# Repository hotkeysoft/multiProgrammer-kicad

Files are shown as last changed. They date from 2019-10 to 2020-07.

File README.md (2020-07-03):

# Multi-Programmer With Serial / SPI Programming
Rev A August 2019

Features
============
- Sockets for direct programming:
	- ATMEGA328P TQFP 32 (via adapter)
	- ATMEGA328P DIP 28 pins
	- ATTINY44/84
	- ATTINY45/85
- Headers for in-circuit programming:
	- Serial Header:
		- 5 pins 2.54mm
	- SPI Headers (too many):
		- 2x3 pins 2.54mm (99% of use)
		- 2x3 pins 1.27mm
		- 1x6 pins 1.25mm (micro-JST)
		- Tag-Connect (mostly useless, since there are no two-ended 
		  Tag-Connect cables. Will be removed in future revisions)
- Two programming modes:
	- Serial passtrough
		- Useful to programm chips with Arduino bootloader, or for any USB<->Serial adapter needs
	- ICSP Programming
		- Compatible with _Arduino as ISP_ programmer in Arduino interface
	- Toggle Serial/ICSP mode with pushbutton switch
- USB-B port (could be a downside but I am fond of them: they are sturdy)

Notes
============
- Socketed chips:
	- _ATmega328P_ running _ArduinoISP_
	- _555_ Used for Mode switch debouncing (old school)
	- _PALCE16V8_ for mode switching logic (LEDs, pin routing) [source](PLD/TTLSW.PDS) 
- Optional crystal socket, not needed for new chips (internal clock is used)
 	- Required for serial programming if the target is set to use an external crystal
	  (Need to confirm if needed in SPI mode)
- Boots in serial mode, be sure to switch mode to use SPI mode
- Reset button resets the target chip (in both modes) and the _Arduino as ISP_ software
- Don't put more than one target chip at a time (undefined behavior, no protection, might destroy the universe)

Images
============

|Render | Real PCB |
|---|---|
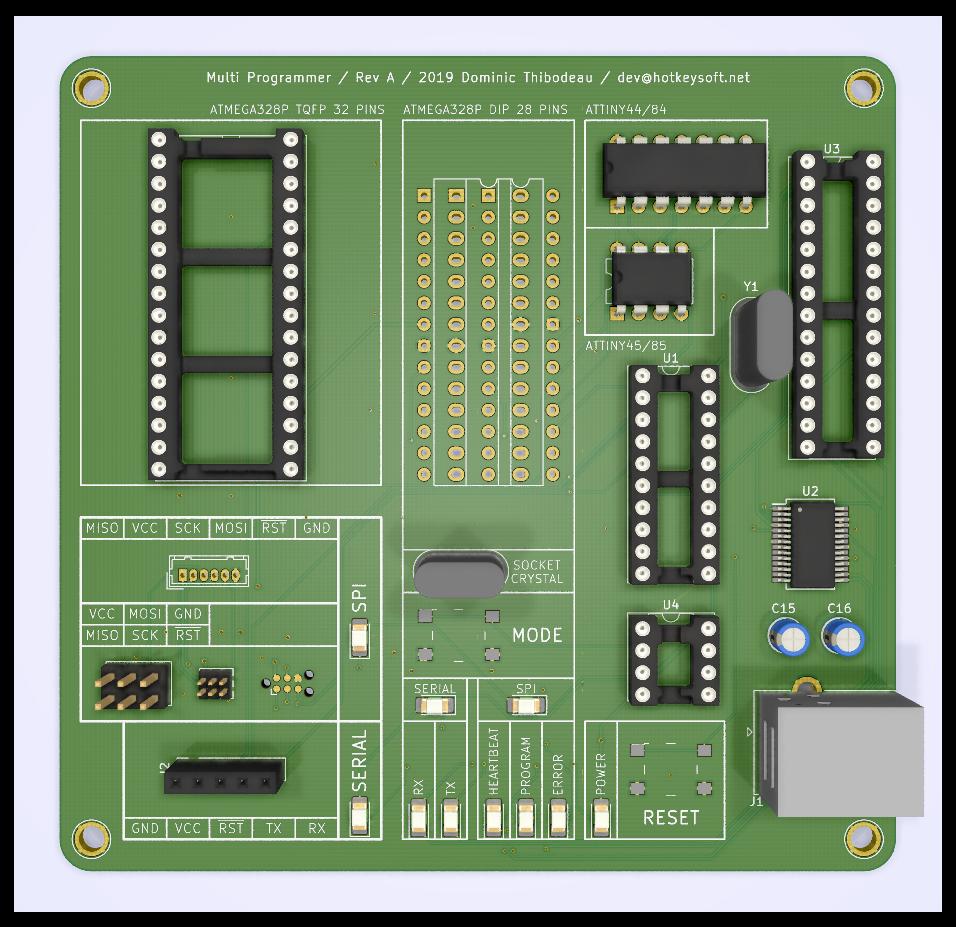
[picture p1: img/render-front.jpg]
Render Front
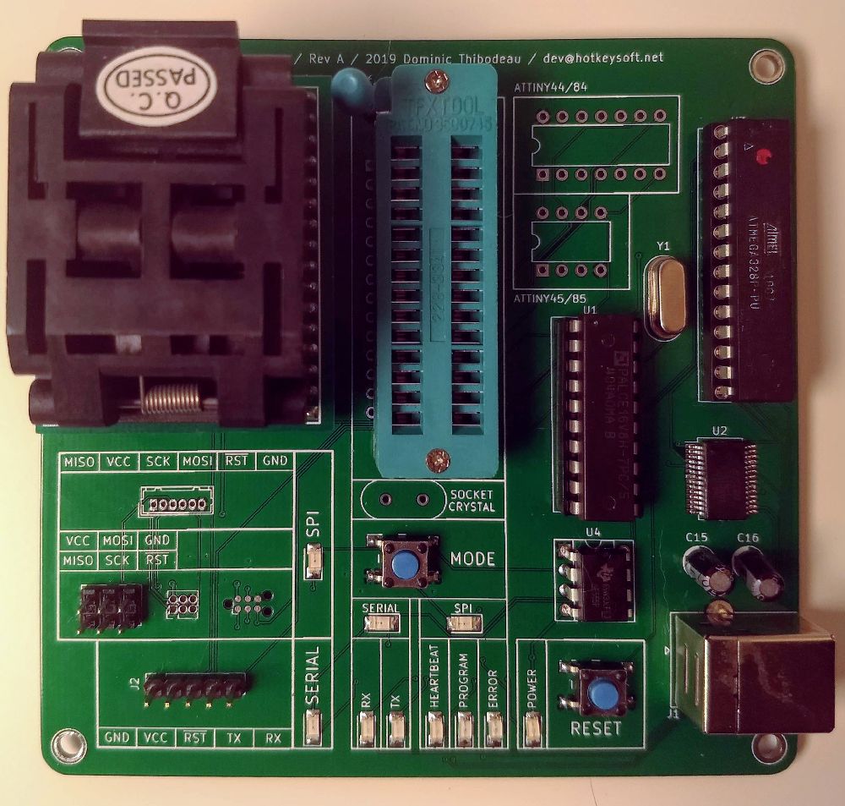
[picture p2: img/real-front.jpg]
Real Front
|||
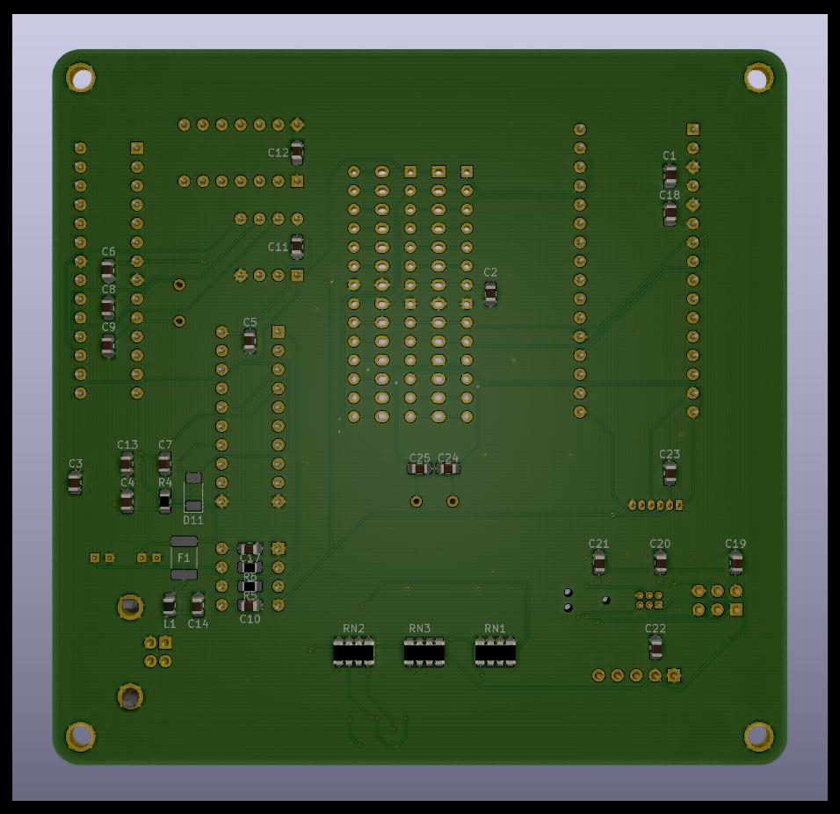
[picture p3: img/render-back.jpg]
Render Back
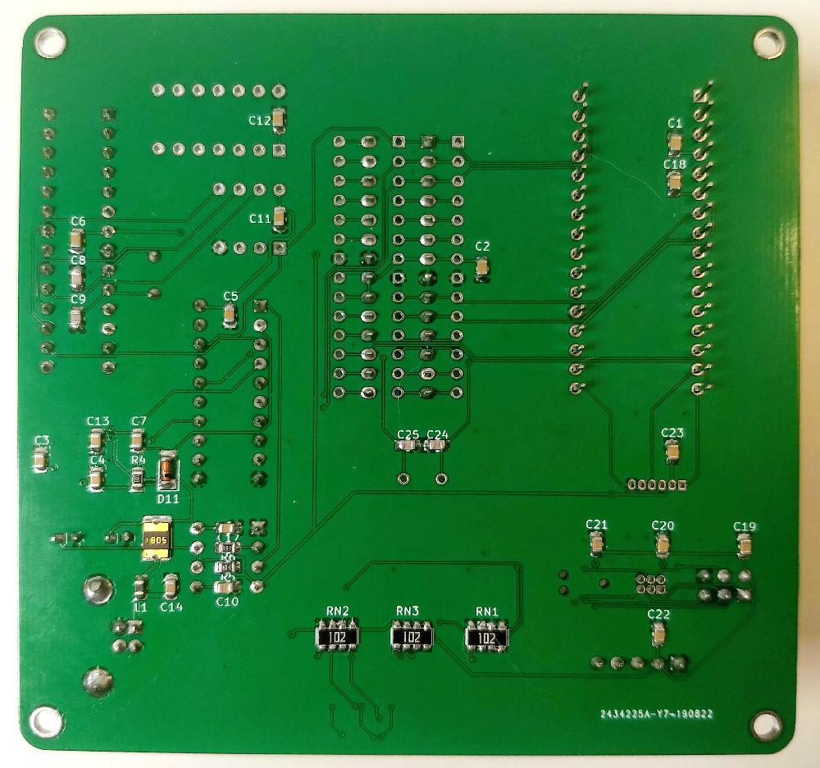
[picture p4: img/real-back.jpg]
Real Back
| | |

### Schematics (pdf)
- [Complete schematics](./img/schema.pdf)

### PCB Images (svg)
- [Top](./img/pcb-front.svg)
- [Bottom](./img/pcb-back.svg)

Future
============
- Try to combine 555 and programmable logic on Arduino
- Remove useless connectors
- Save mode in EEPROM so it is remembered on next power-up
- LEDs are too bright

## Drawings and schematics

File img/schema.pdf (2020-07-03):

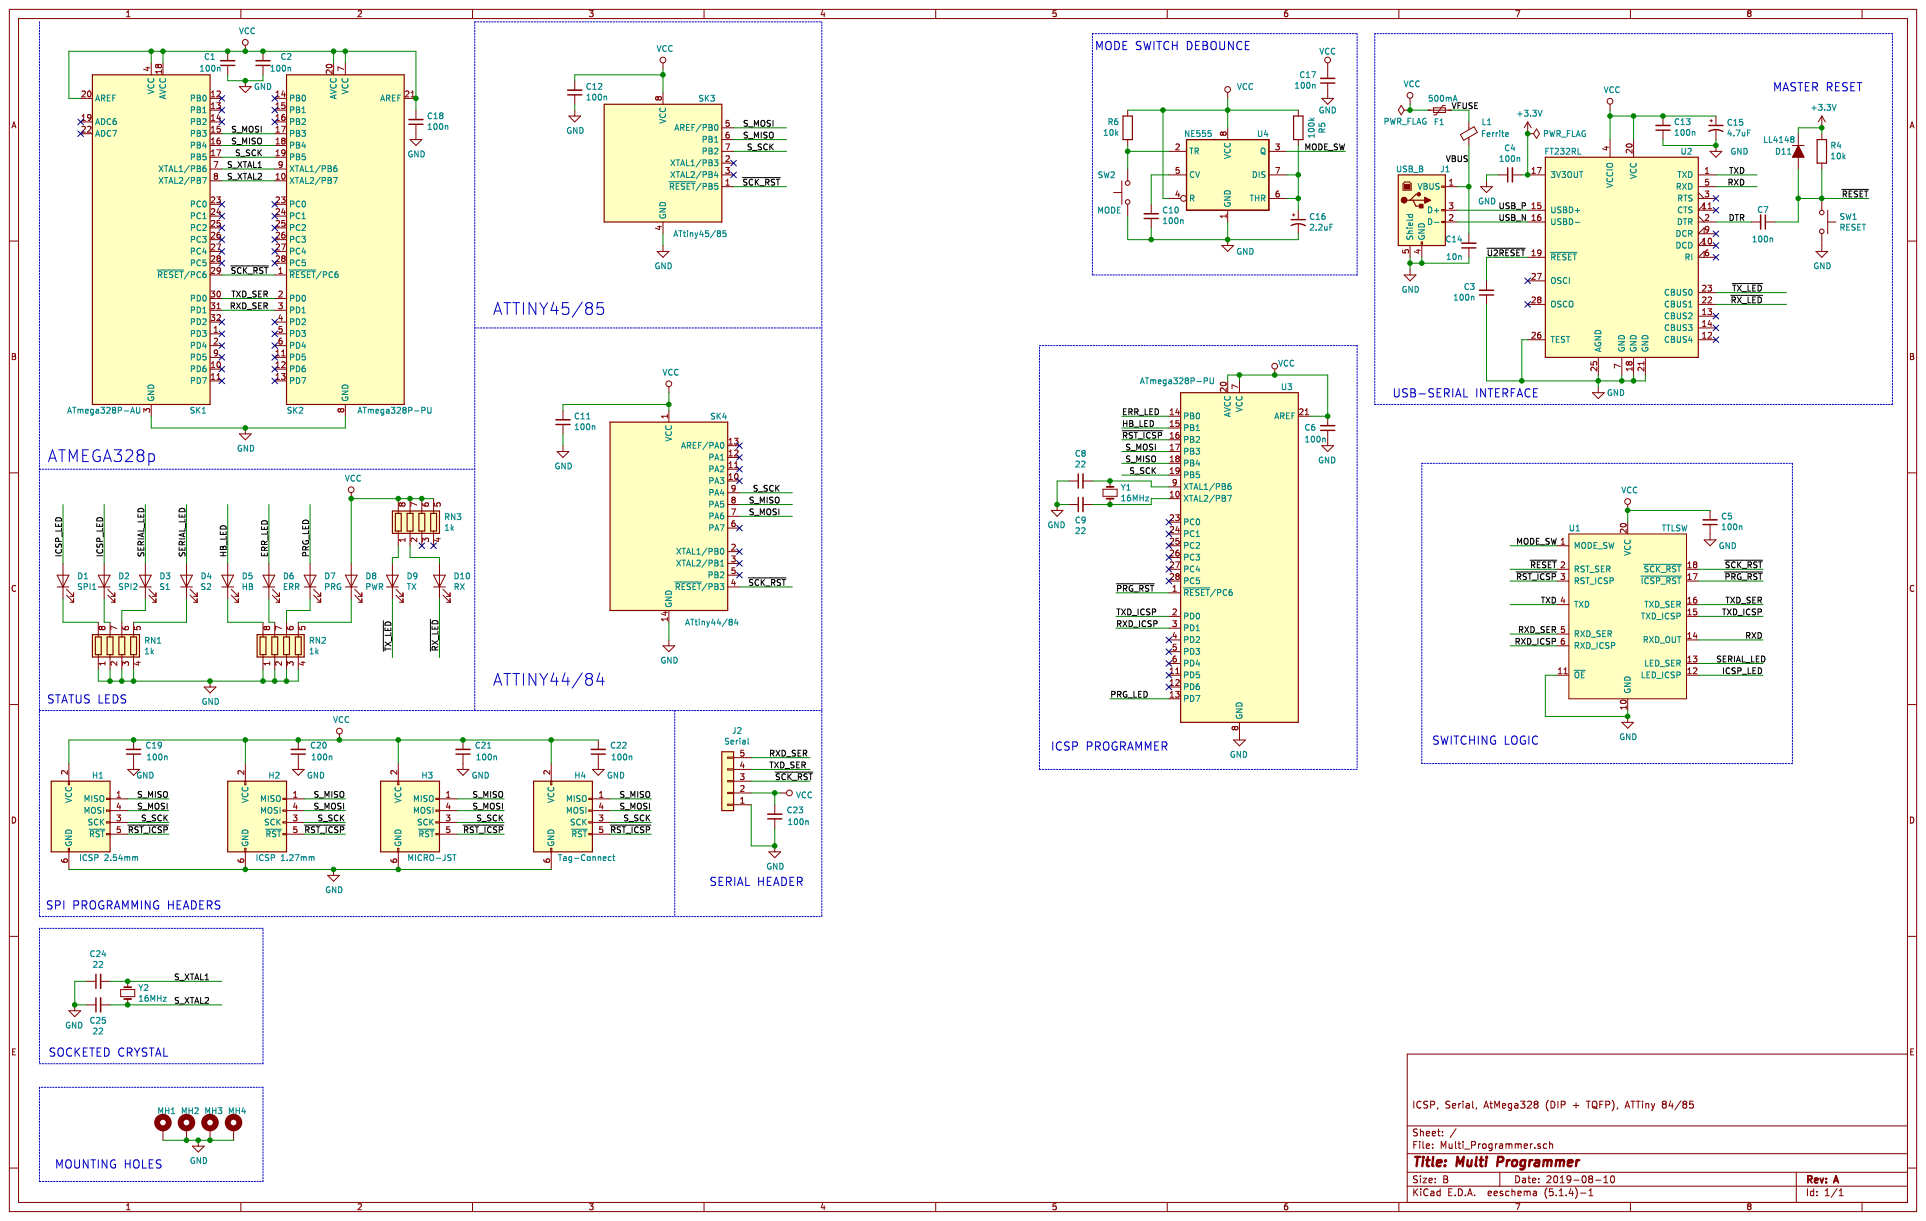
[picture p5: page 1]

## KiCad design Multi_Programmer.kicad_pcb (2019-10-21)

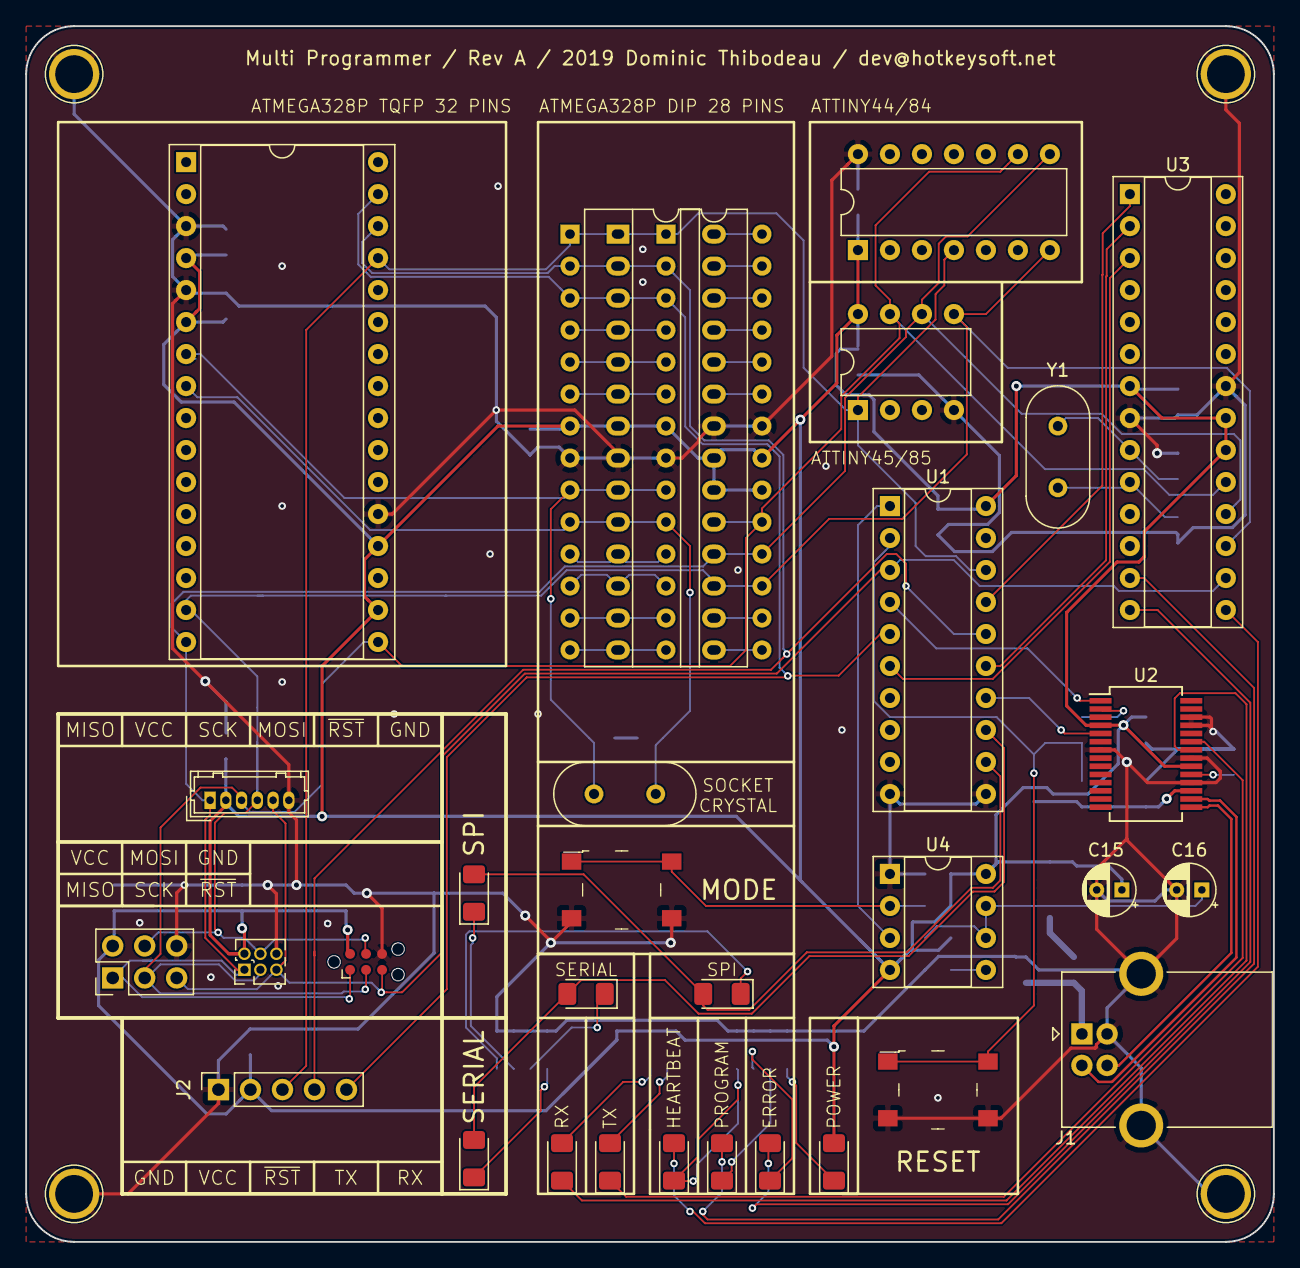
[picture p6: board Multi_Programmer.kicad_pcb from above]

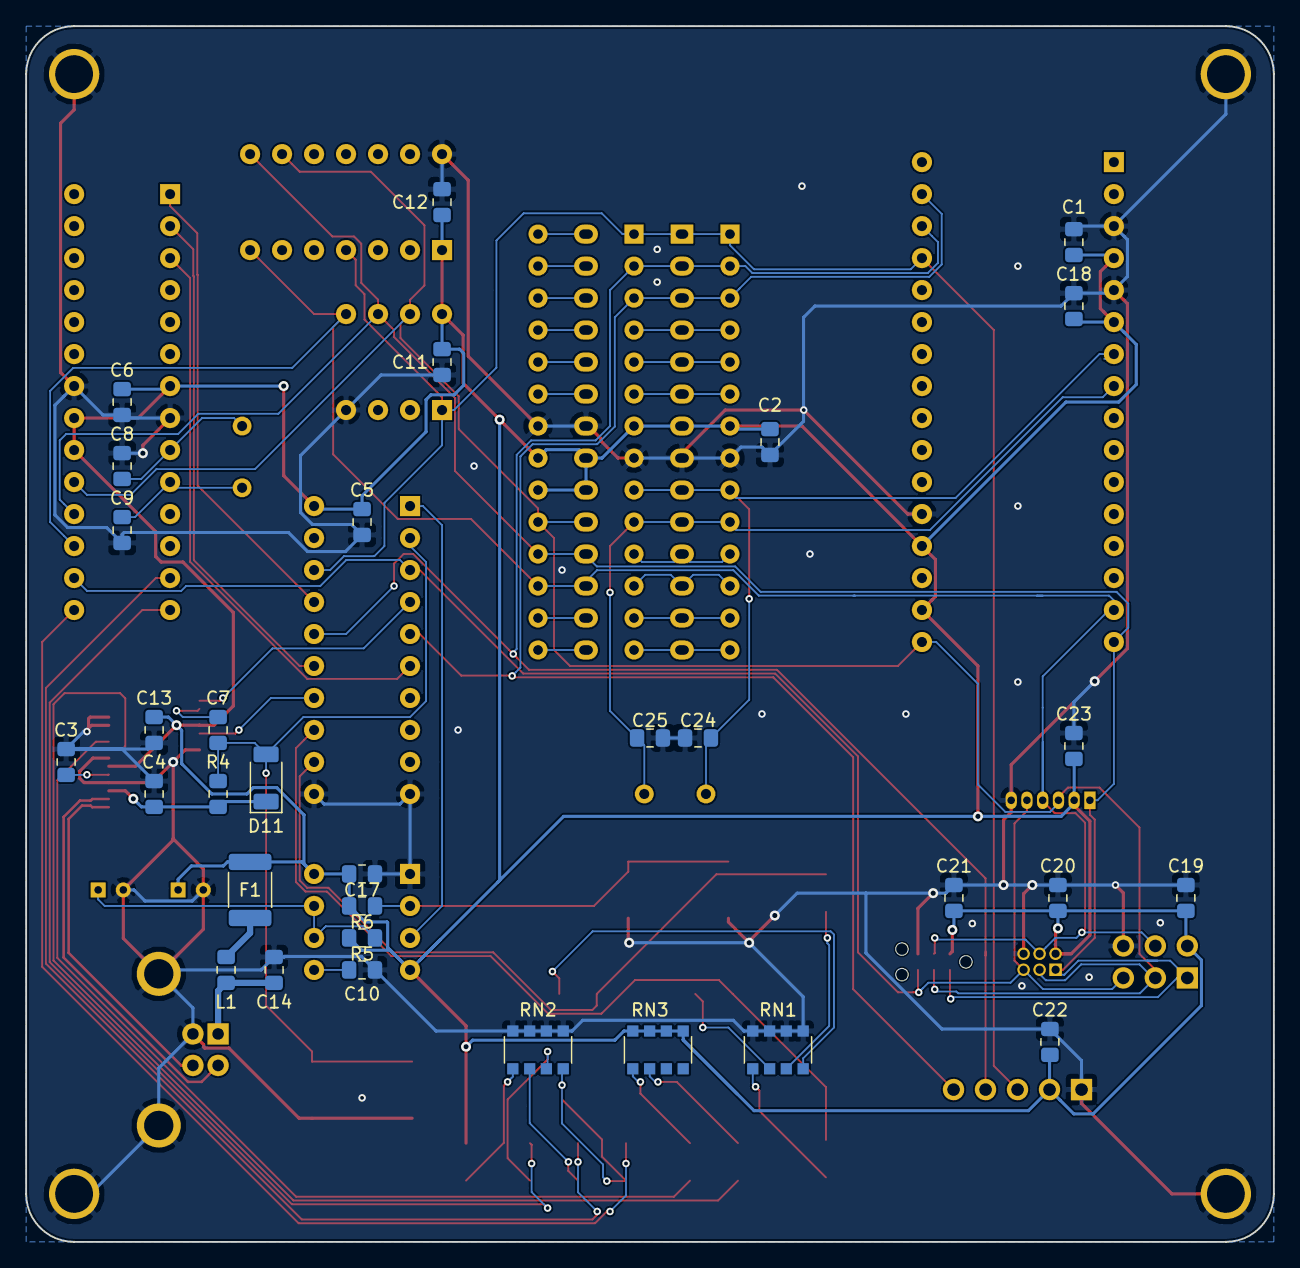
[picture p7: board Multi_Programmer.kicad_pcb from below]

Board: 2 copper layers, 99.1 x 96.5 mm, 66 parts (32 on the bottom side), 47 nets.

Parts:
C1, C2, C3, C4, C5, C6, C7, C10, C11, C12, C13, C17, C18, C19, C20, C21, C22, C23: 100n; C_0805_2012Metric_Pad1.15x1.40mm_HandSolder
C8, C9, C24, C25: 22; C_0805_2012Metric_Pad1.15x1.40mm_HandSolder
C14: 10n; C_0805_2012Metric_Pad1.15x1.40mm_HandSolder
C15: 4.7uF; CP_Radial_D4.0mm_P2.00mm
C16: 2.2uF; CP_Radial_D4.0mm_P2.00mm
D1: SPI1; LED_1206_3216Metric_Pad1.42x1.75mm_HandSolder
D2: SPI2; LED_1206_3216Metric_Pad1.42x1.75mm_HandSolder
D3: S1; LED_1206_3216Metric_Pad1.42x1.75mm_HandSolder
D4: S2; LED_1206_3216Metric_Pad1.42x1.75mm_HandSolder
D5: HB; LED_1206_3216Metric_Pad1.42x1.75mm_HandSolder
D6: ERR; LED_1206_3216Metric_Pad1.42x1.75mm_HandSolder
D7: PRG; LED_1206_3216Metric_Pad1.42x1.75mm_HandSolder
D8: PWR; LED_1206_3216Metric_Pad1.42x1.75mm_HandSolder
D9: TX; LED_1206_3216Metric_Pad1.42x1.75mm_HandSolder
D10: RX; LED_1206_3216Metric_Pad1.42x1.75mm_HandSolder
D11: LL4148; SOD80
F1: 500mA; Fuse_1812_4532Metric_Pad1.30x3.40mm_HandSolder
H1: ICSP 2.54mm; PinHeader_2x03_P2.54mm_Vertical
H2: ICSP 1.27mm; PinHeader_2x03_P1.27mm_Vertical
H3: MICRO-JST; Hirose_DF13-06P-1.25DSA_1x06_P1.25mm_Vertical
H4: Tag-Connect; Tag-Connect_TC2030-IDC-NL_2x03_P1.27mm_Vertical
J1: USB_B; USB_B_OST_USB-B1HSxx_Horizontal
J2: Serial; PinSocket_1x05_P2.54mm_Vertical
L1: Ferrite; L_0805_2012Metric_Pad1.15x1.40mm_HandSolder
MH1, MH2, MH3, MH4: MountingHole; TestPoint_Plated_Hole_D3.0mm
R4, R6: 10k; R_0805_2012Metric_Pad1.15x1.40mm_HandSolder
R5: 100k; R_0805_2012Metric_Pad1.15x1.40mm_HandSolder
RN1, RN2, RN3: 1k; R_Array_Convex_4x1206
SK1: ATmega328P-AU; DIP-32_W15.24mm_Socket
SK2: ATmega328P-PU; DIP-28_Zif_Multi
SK3: ATtiny45/85; DIP-8_W7.62mm
SK4: ATtiny44/84; DIP-14_W7.62mm
SW1: RESET; Switch_Tactile_SMD_6x6mm_PTS645
SW2: MODE; Switch_Tactile_SMD_6x6mm_PTS645
U1: TTLSW; DIP-20_W7.62mm_Socket
U2: FT232RL; SSOP-28_5.3x10.2mm_P0.65mm
U3: ATmega328P-PU; DIP-28_W7.62mm_Socket
U4: NE555; DIP-8_W7.62mm_Socket
Y1, Y2: 16MHz; Crystal_HC18-U_Vertical

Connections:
+3V3: C4.2, D11.1, R4.2, U2.17
/DTR: C7.2, U2.2
/ERR_LED: D6.2, U3.14
/HB_LED: D5.2, U3.15
/ICSP_LED: D1.2, D2.2, U1.12
/MODE_SW: U1.1, U4.3
/PRG_LED: D7.2, U3.13
/RXD: U1.14, U2.5
/RXD_ICSP: U1.6, U3.3
/RXD_SER: J2.5, SK1.31, SK2.3, U1.5
/SERIAL_LED: D3.2, D4.2, U1.13
/S_MISO: H1.1, H2.1, H3.1, H4.1, SK1.16, SK2.18, SK3.6, SK4.8, U3.18
/S_MOSI: H1.4, H2.4, H3.4, H4.4, SK1.15, SK2.17, SK3.5, SK4.7, U3.17
/S_SCK: H1.3, H2.3, H3.3, H4.3, SK1.17, SK2.19, SK3.7, SK4.9, U3.19
/S_XTAL1: C24.2, SK1.7, SK2.9, Y2.1
/S_XTAL2: C25.2, SK1.8, SK2.10, Y2.2
/TXD: U1.4, U2.1
/TXD_ICSP: U1.15, U3.2
/TXD_SER: J2.4, SK1.30, SK2.2, U1.16
/USB_N: J1.2, U2.16
/USB_P: J1.3, U2.15
/VBUS: C14.2, J1.1, L1.2
/VFUSE: F1.1, L1.1
/~PRG_RST: U1.17, U3.1
/~RESET: C7.1, D11.2, R4.1, SW1.1, U1.2
/~RST_ICSP: H1.5, H2.5, H3.5, H4.5, U1.3, U3.16
/~RX_LED: D10.1, U2.22
/~SCK_RST: J2.3, SK1.29, SK2.1, SK3.1, SK4.4, U1.18
/~TX_LED: D9.1, U2.23
/~U2RESET: C3.2, U2.19
GND: C1.1, C2.1, C3.1, C4.1, C5.1, C6.1, C8.1, C9.1, C10.1, C11.1, C12.1, C13.1, C14.1, C15.2, C16.2, C17.1, C18.1, C19.1, C20.1, C21.1, C22.1, C23.1, C24.1, C25.1, H1.6, H2.6, H3.6, H4.6, J1.4, J1.5, J2.1, MH1.1, MH2.1, MH3.1, MH4.1, RN1.1, RN1.2, RN1.3, RN1.4, RN2.1, RN2.2, RN2.3, RN2.4, SK1.3, SK1.5, SK1.21, SK2.8, SK2.22, SK3.4, SK4.14, SW1.2, SW2.2, U1.10, U1.11, U2.7, U2.18, U2.21, U2.25, U2.26, U3.8, U3.22, U4.1
unnamed: C8.2, U3.9, Y1.1
unnamed: C9.2, U3.10, Y1.2
unnamed: C10.2, U4.5
unnamed: C16.1, R5.1, U4.6, U4.7
unnamed: D1.1, RN1.8
unnamed: D2.1, RN1.7
unnamed: D3.1, RN1.6
unnamed: D4.1, RN1.5
unnamed: D5.1, RN2.8
unnamed: D6.1, RN2.7
unnamed: D7.1, RN2.6
unnamed: D8.1, RN2.5
unnamed: D9.2, RN3.1
unnamed: D10.2, RN3.2
unnamed: R6.1, SW2.1, U4.2
VCC: C1.2, C2.2, C5.2, C6.2, C11.2, C12.2, C13.2, C15.1, C17.2, C18.2, C19.2, C20.2, C21.2, C22.2, C23.2, D8.2, F1.2, H1.2, H2.2, H3.2, H4.2, J2.2, R5.2, R6.2, RN3.5, RN3.6, RN3.7, RN3.8, SK1.4, SK1.6, SK1.18, SK1.20, SK2.7, SK2.20, SK2.21, SK3.8, SK4.1, U1.20, U2.4, U2.20, U3.7, U3.20, U3.21, U4.4, U4.8

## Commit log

2019-08-14 Initial import
    [Multi Programmer.kicad_pcb, Multi Programmer.sch]
2019-08-14 Added sockets for attiny, move sockets to separate page
    [Multi Programmer.kicad_pcb, Multi Programmer.sch, Sockets.sch]
2019-08-14 Round edges
    [Multi Programmer-B.Cu.gbr, Multi Programmer-B.Mask.gbr, Multi Programmer-B.SilkS.gbr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]
2019-08-17 Repositioned crystal
    [Multi Programmer-B.Cu.gbr, Multi Programmer-B.Mask.gbr, Multi Programmer-B.SilkS.gbr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]
2019-08-23 Add PCB Fabrication zip files
2020-07-03 Cleanup, added images
    [Multi_Programmer.kicad_pcb, Multi_Programmer.sch]
2020-07-03 Renamed project
    [Multi_Programmer-B.Cu.gbr, Multi_Programmer-B.Mask.gbr, Multi_Programmer-B.SilkS.gbr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]
2020-07-03 Fixed names
    [Multi_Programmer-Edge.Cuts.gbr, Multi_Programmer-F.Cu.gbr, Multi_Programmer-F.Mask.gbr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]
